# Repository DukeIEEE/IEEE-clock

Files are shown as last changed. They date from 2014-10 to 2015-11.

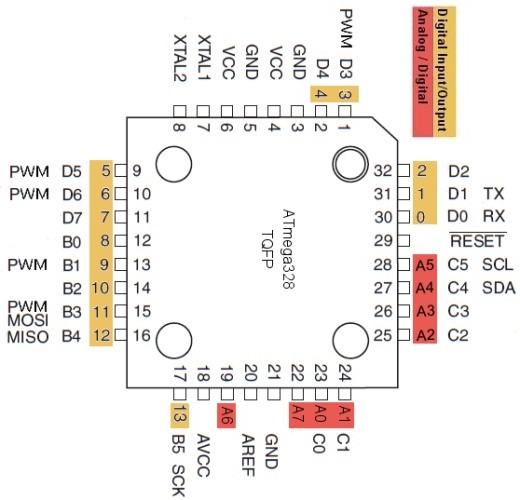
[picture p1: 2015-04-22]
final schematics/atmega328-tqfp-arduino-pinout.jpg

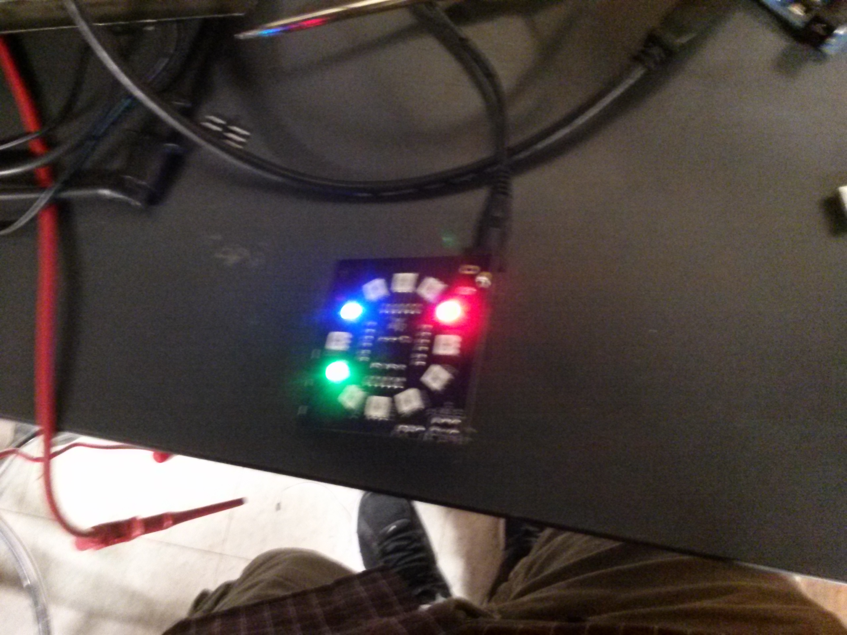
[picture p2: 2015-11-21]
CAM00366.jpg

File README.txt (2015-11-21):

Analog LED clock

This is a project to create a programmable clock using LEDs to represent numbers and hand movements.

Contents:

AnalogClock - Arduino code
Designs - Clock designs for laser cutting
Schematics - PCB schematics and boards
Proposal - Contains a timeline for this workshop
Documents - Contains BOM and datasheets

Programming using arduino-1.0.1 and Arduino UNO programmer:

Place atmega into programmer
Connect all wires except reset to PCB
Upload ArduinoISP -- UNO, Arduino as ISP
Burn bootloader -- Arduino328, Arduino as ISP

Remove atmega from programmer
Connect reset wire
Run a sketch -- Arduino328, AVRISP mkII

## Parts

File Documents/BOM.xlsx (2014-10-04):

4 tactile switches | http://www.digikey.com/product-detail/en/1825910-6/450-1650-ND/1632536
attiny84 | http://www.digikey.com/product-detail/en/ATTINY84-20PU/ATTINY84-20PU-ND/1245916
quartz crystal | http://www.digikey.com/product-highlights/us/en/ecs-international-ecx-crystals/1266
clock chip | http://www.digikey.com/product-detail/en/DS1302S%2BT%26R/DS1302S%2BT%26RTR-ND/1196878

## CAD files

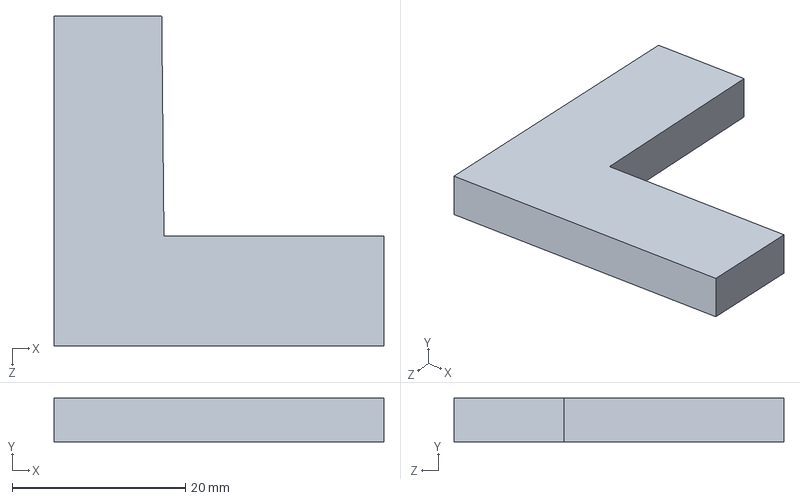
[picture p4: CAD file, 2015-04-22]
Reflow_solder_stencils/Part1.SLDPRT
38.1 x 5.08 x 38.1 mm

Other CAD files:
Designs/Clock_DukeIEEE.dwg
Reflow_solder_stencils/pcb_jig.dwg
Designs/Clock_IEEE.dwg
Designs/Stand_Updated.dwg
Designs/Clock_IEEE_clean.dwg
Designs/Clock_DukeIEEE_clean.dwg
Designs/Basic_Stand_Updated.dwg
Designs/Clock_Duke.dwg
Designs/Clock_Duke_Name.dwg
Designs/Clock_Tom.dwg
Designs/Basic_Stand.dwg
Designs/Clock_Tom2.dwg
Designs/Basic.dwg
Designs/Basic with Screws.dwg
Reflow_solder_stencils/Part1.STL

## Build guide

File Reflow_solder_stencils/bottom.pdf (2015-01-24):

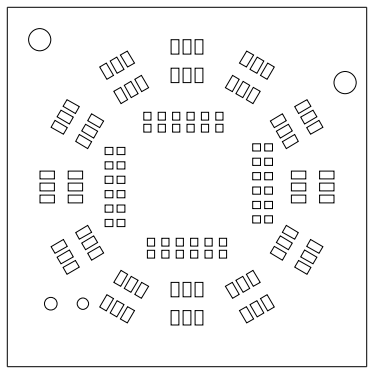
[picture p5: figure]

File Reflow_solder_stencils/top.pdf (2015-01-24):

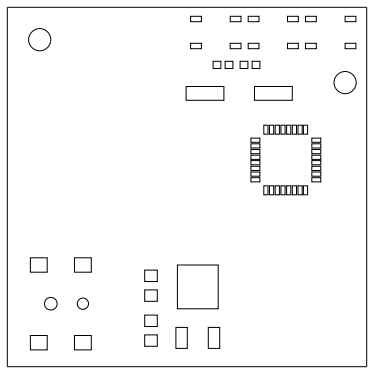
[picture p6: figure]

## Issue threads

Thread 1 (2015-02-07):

how 2 test clock

Ningrui-Li, 2015-02-07:
1. get tom's special version of arduino
2. run strandtest from the Adafrult neopixel libraries.
3. change pin to 5 then upload
4. make sure power pin is connected between clock board and arduino. on clock board, white wire is connected to pin furthest away from the 1 in "ISP1". also black = ground, white = 5 V on arduino.
5. touch red dangling wire to outer middle pin of LED 10 (should be a wire sticking out of it to make this easy)

TomWoo, 2015-04-22:
:+1:

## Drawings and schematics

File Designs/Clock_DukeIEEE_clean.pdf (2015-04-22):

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

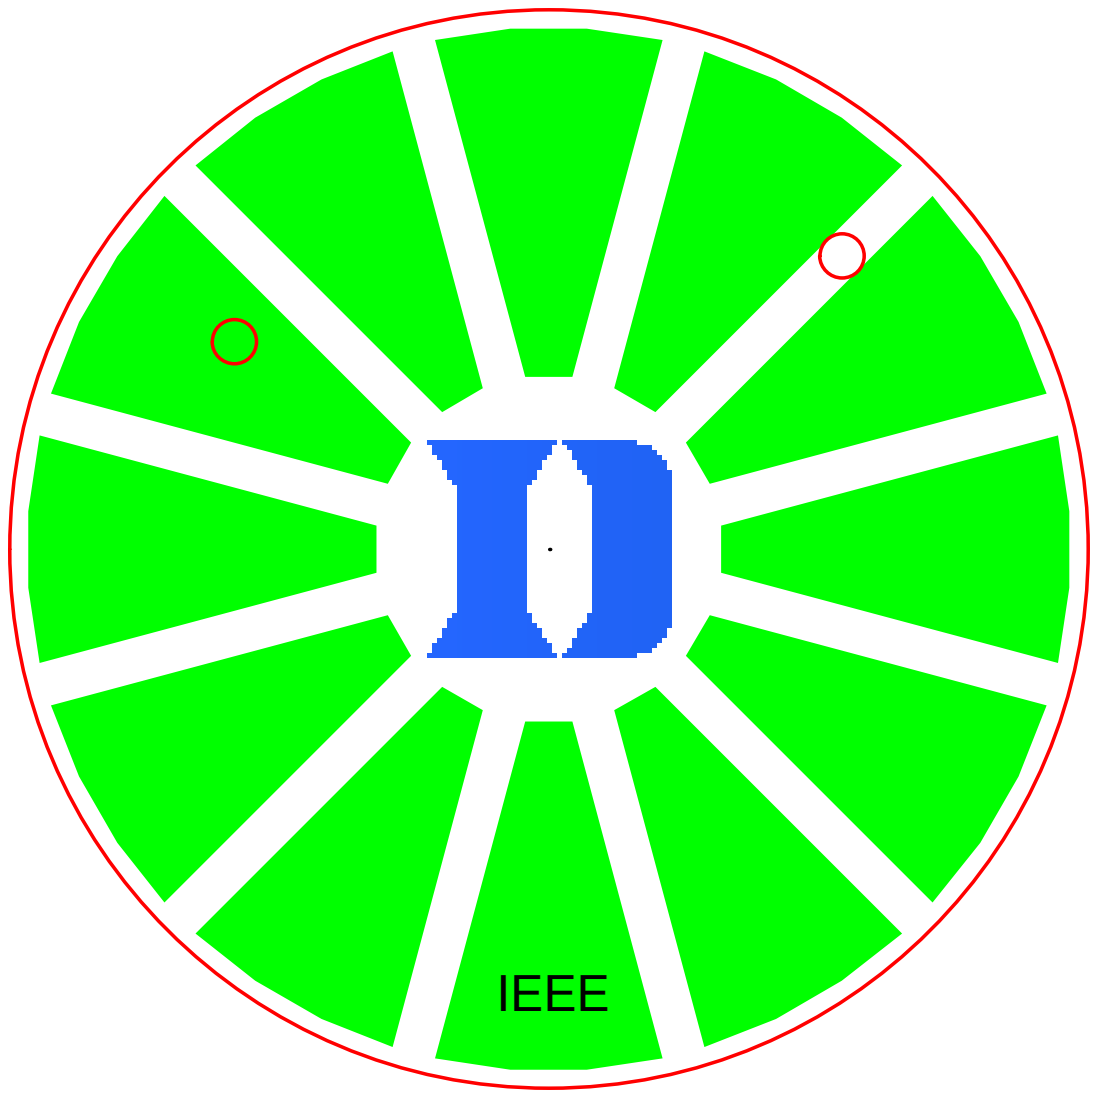
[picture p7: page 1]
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

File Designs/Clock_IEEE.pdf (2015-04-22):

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

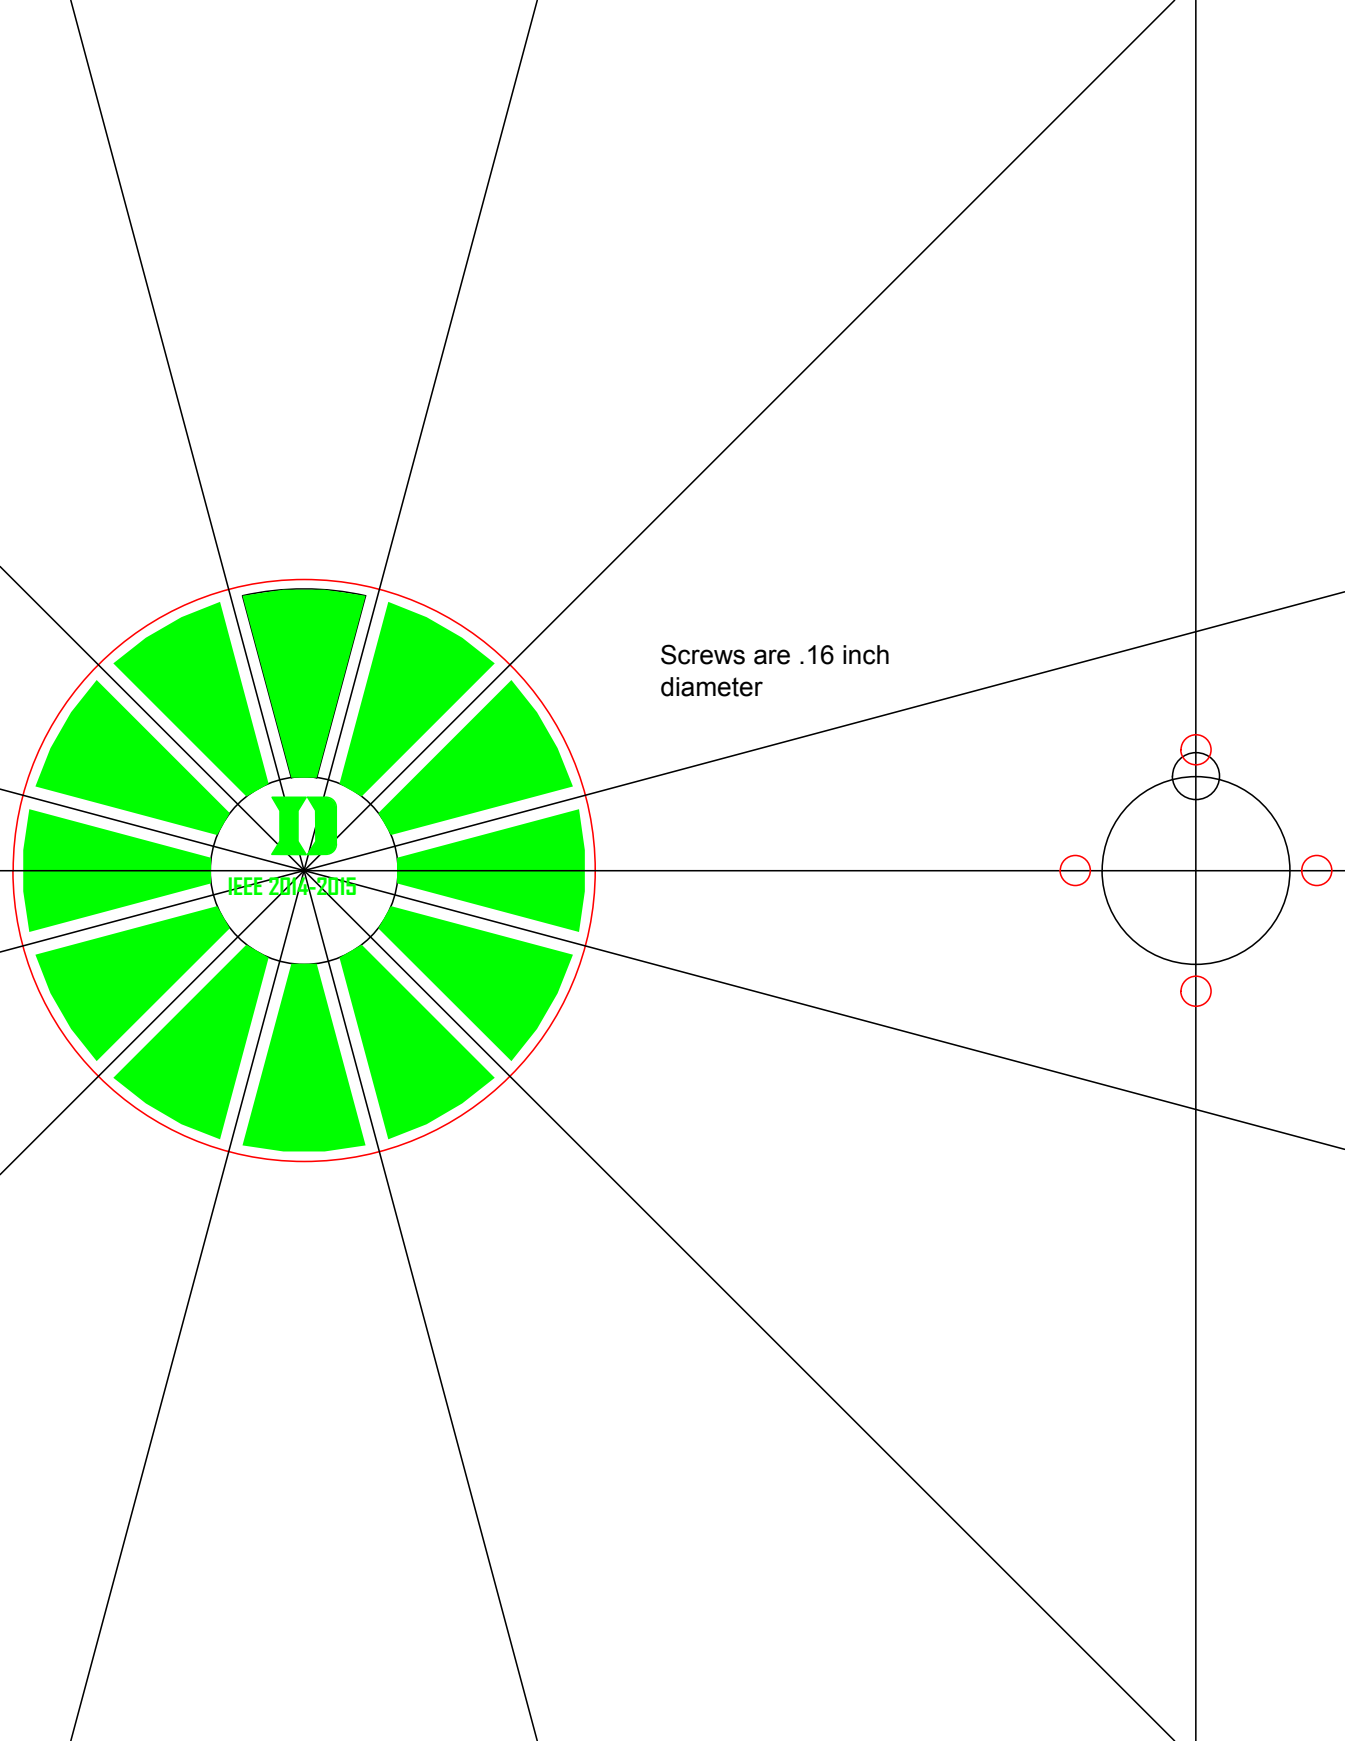
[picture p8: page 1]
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

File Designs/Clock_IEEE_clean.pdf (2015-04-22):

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

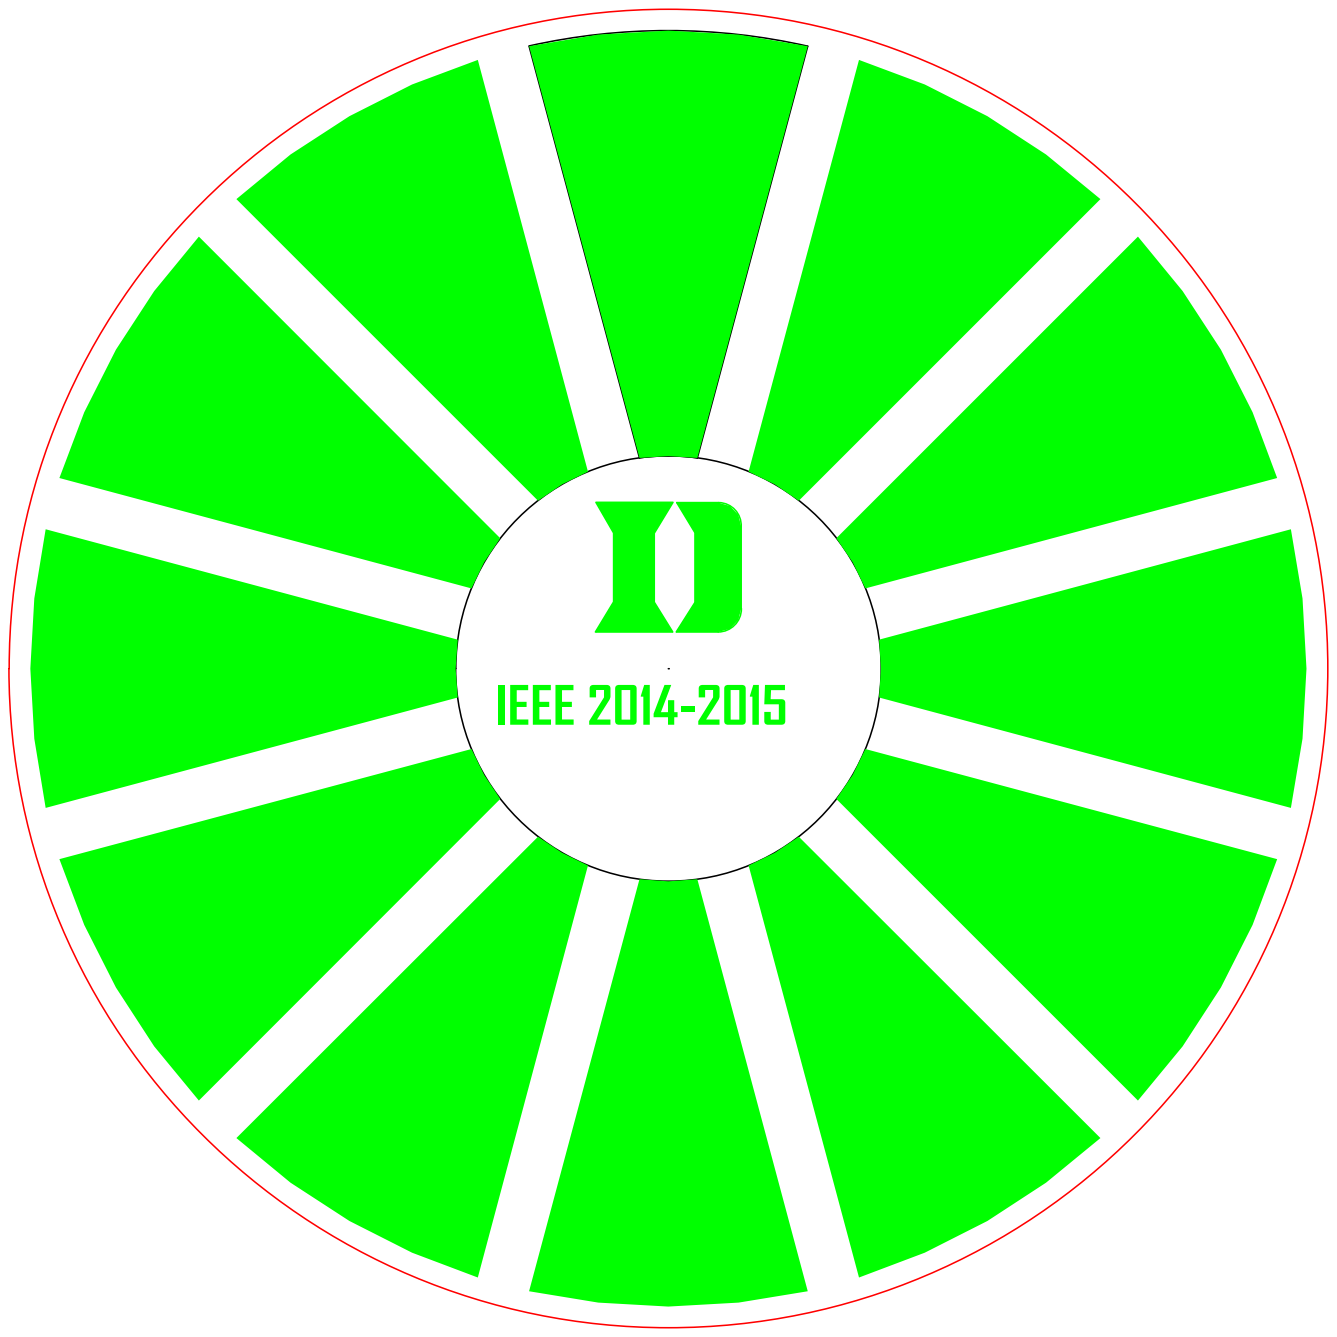
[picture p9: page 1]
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

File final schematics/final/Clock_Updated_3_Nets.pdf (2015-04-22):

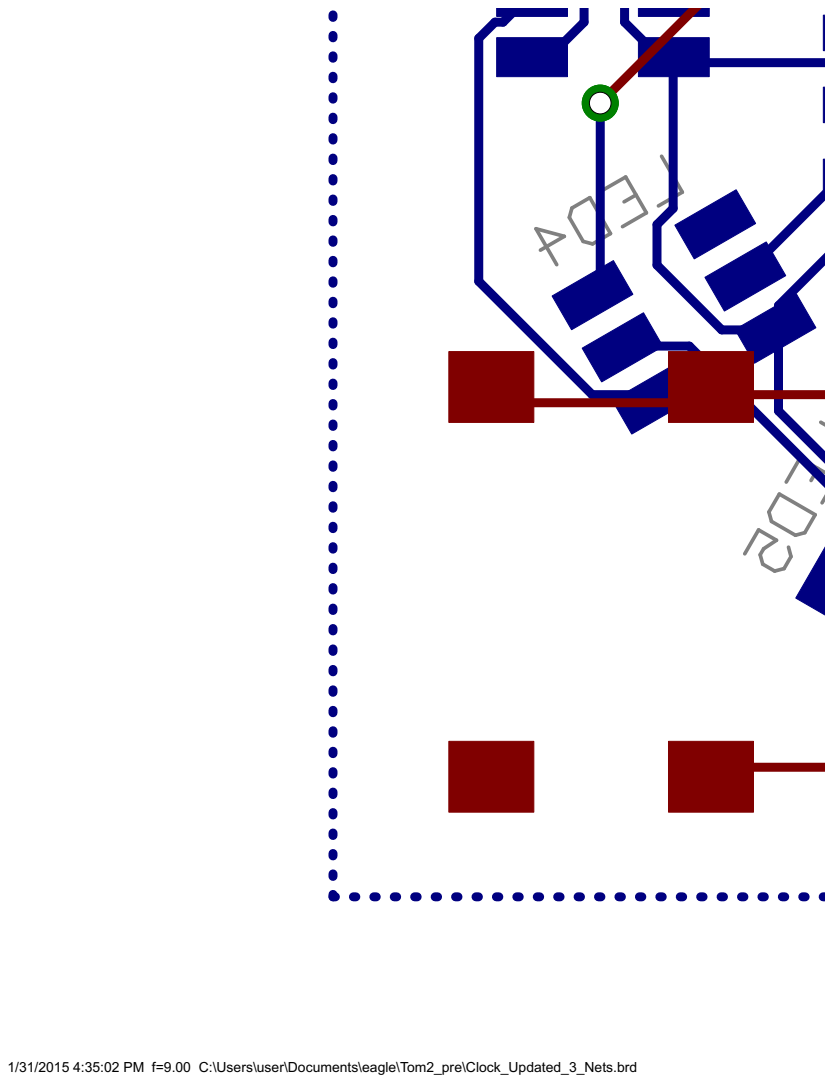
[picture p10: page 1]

1/31/2015 4:35:02 PM f=9.00 C:\Users\user\Documents\eagle\Tom2_pre\Clock_Updated_3_Nets.brd

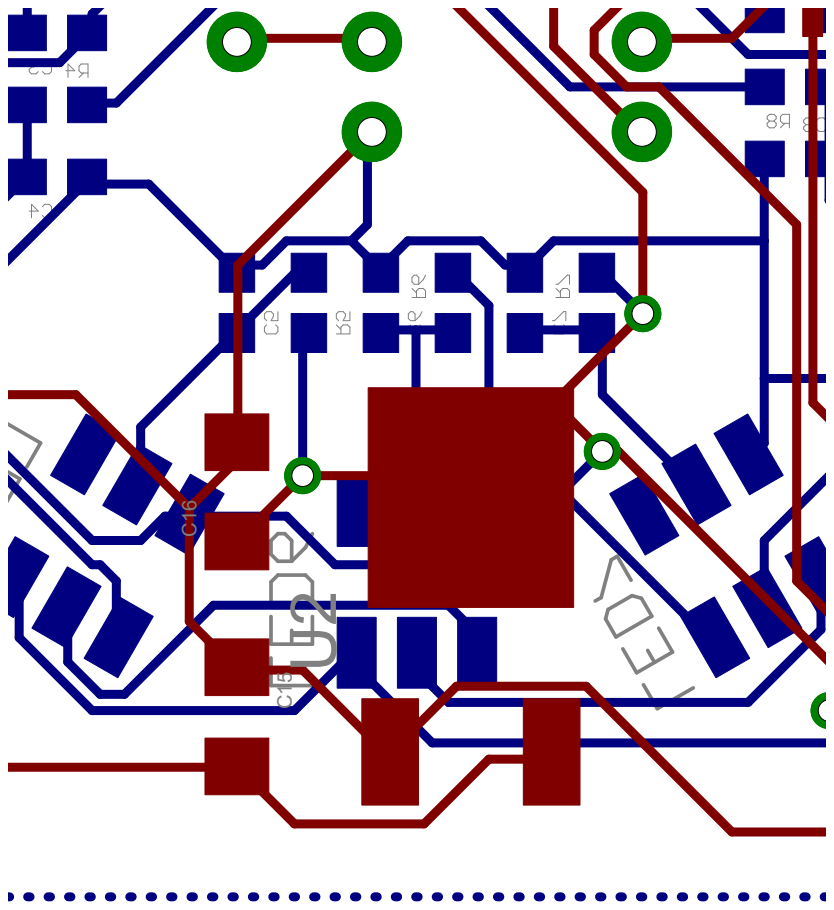
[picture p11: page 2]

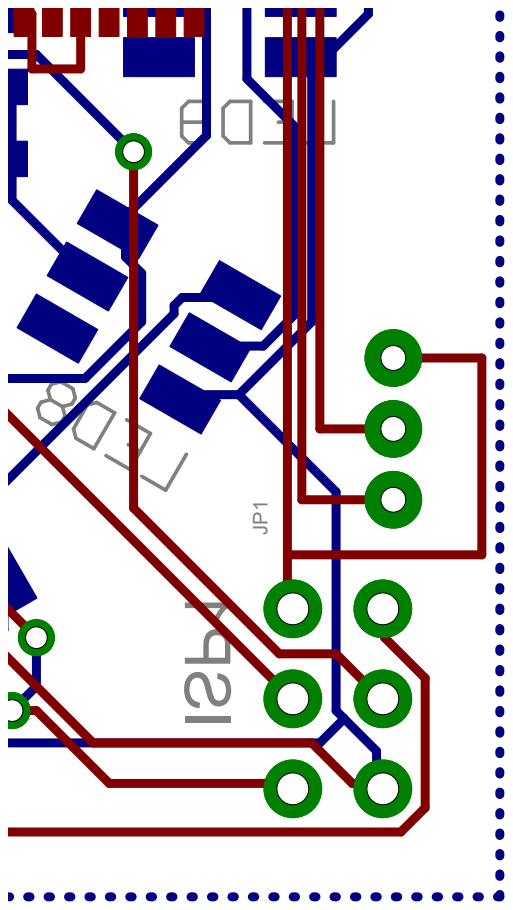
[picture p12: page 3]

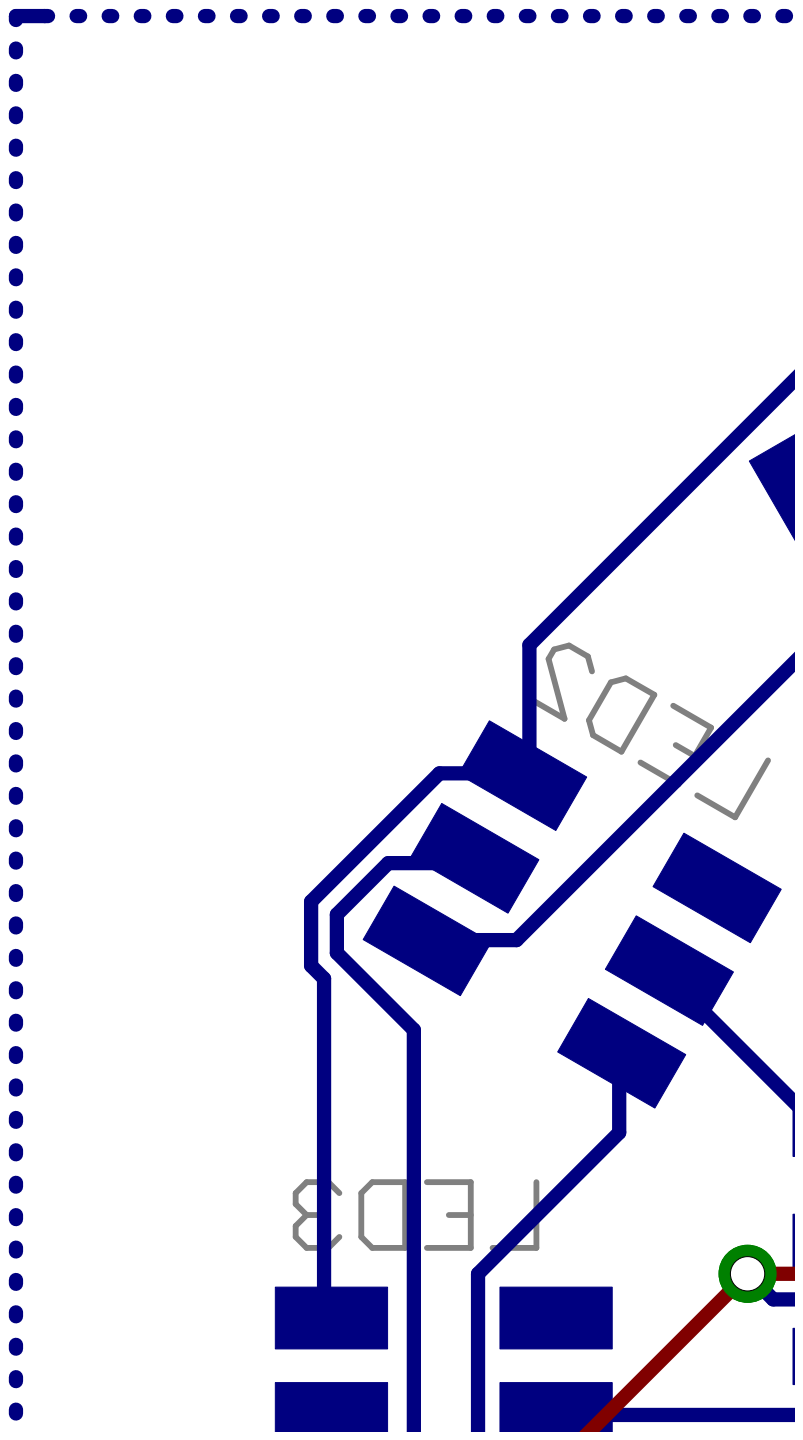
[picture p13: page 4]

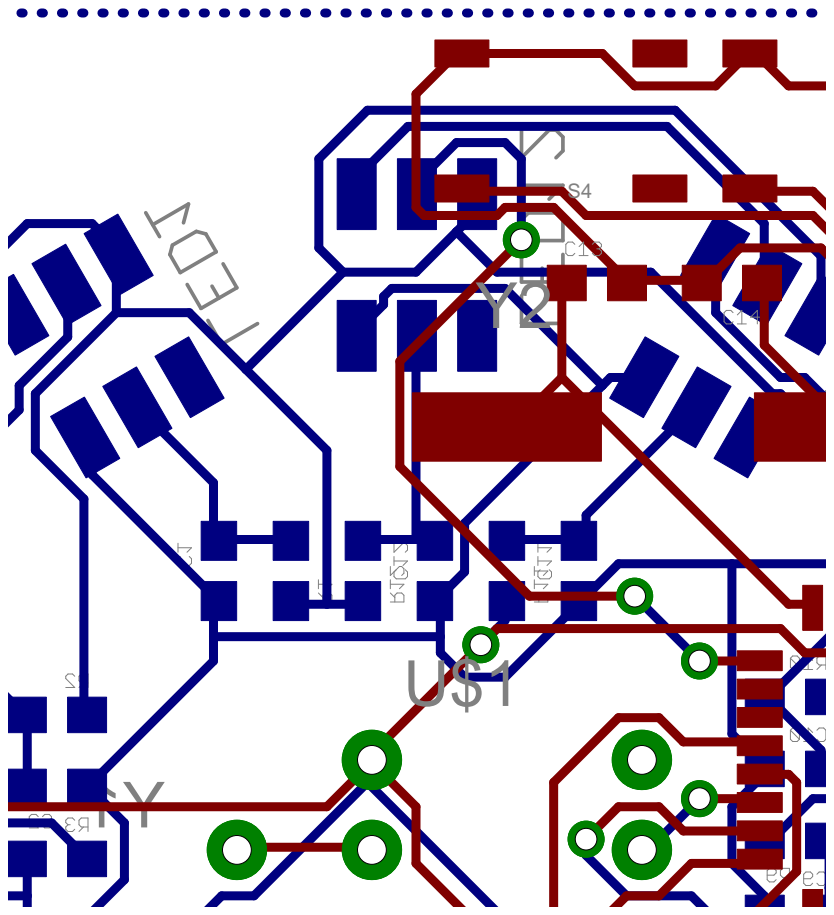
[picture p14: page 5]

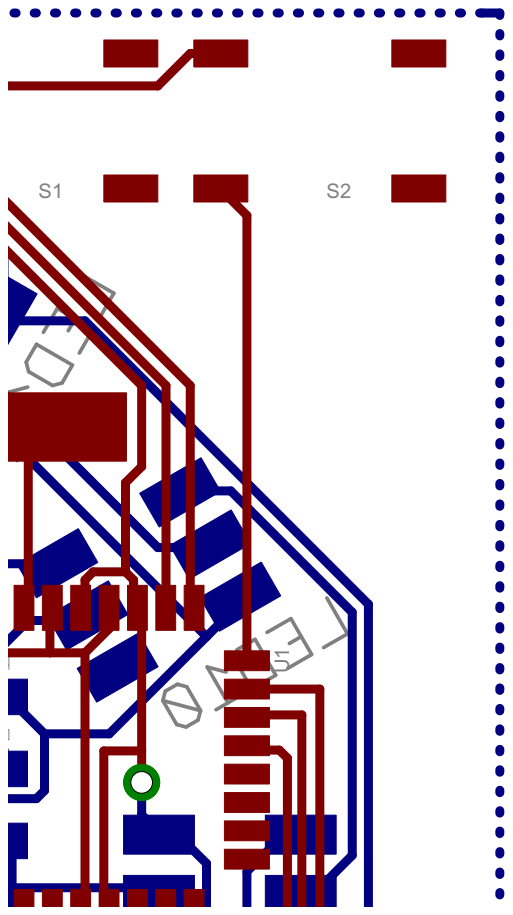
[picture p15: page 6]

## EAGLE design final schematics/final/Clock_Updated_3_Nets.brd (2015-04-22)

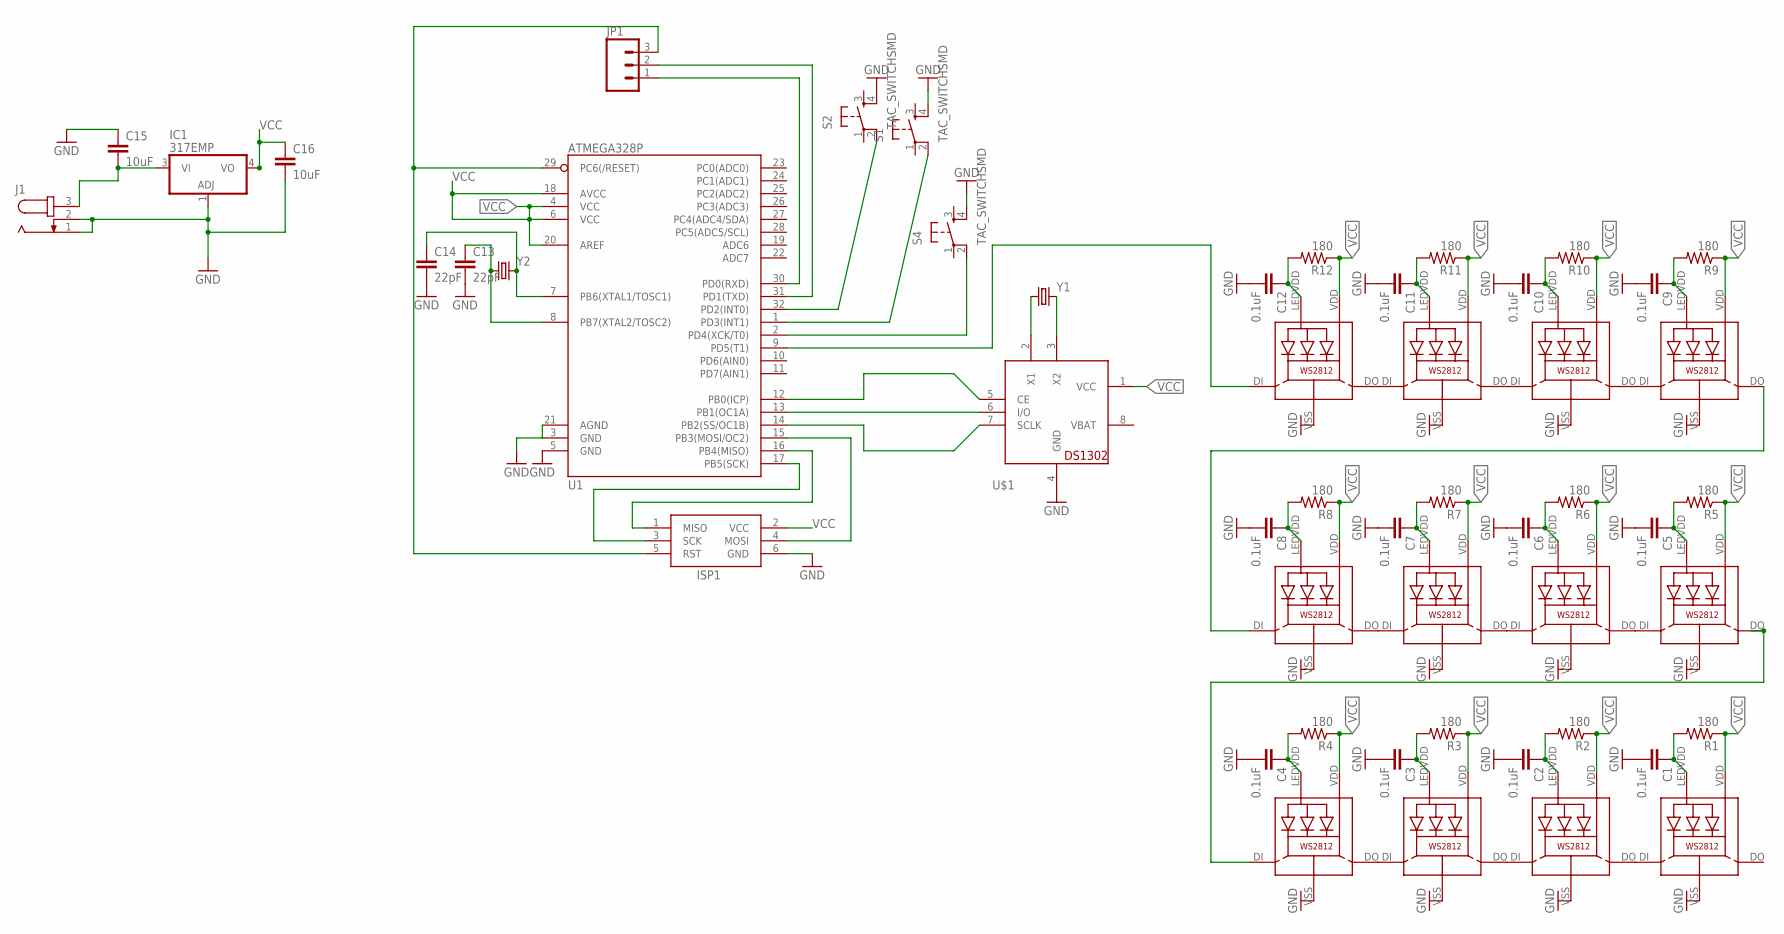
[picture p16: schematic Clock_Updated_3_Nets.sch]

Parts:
C1, C2, C3, C4, C5, C6, C7, C8, C9, C10, C11, C12: 0.1uF; 0603-CAP
C13, C14: 22pF; 0603-CAP
C15, C16: 10uF; 1206
IC1: 317EMP; SOT223
ISP1: AVRISP-6; AVRISP
J1: JACK-PLUG0; SPC4077
JP1: M03JST-PTH-VERT; JST-3-PTH-VERT
LED1, LED2, LED3, LED4, LED5, LED6, LED7, LED8, LED9, LED10, LED11, LED12: WS2812
R1, R2, R3, R4, R5, R6, R7, R8, R9, R10, R11, R12: 180; 0603-RES
S1, S2, S4: TAC_SWITCHSMD; TACTILE-SWITCH-SMD
U1: ATMEGA328P; TQFP32-08
U$1: DS1302; DIL08-ROUND
Y1: CRYSTALTC38H; TC38H
Y2: CRYSTALSMD; HC49UP

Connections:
GND: C1.2, C2.2, C3.2, C4.2, C5.2, C6.2, C7.2, C8.2, C9.2, C10.2, C11.2, C12.2, C13.2, C14.2, C15.1, C16.2, IC1.1 (ADJ), ISP1.6 (GND), J1.1, J1.2, LED1.VSS (GND), LED2.VSS (GND), LED3.VSS (GND), LED4.VSS (GND), LED5.VSS (GND), LED6.VSS (GND), LED7.VSS (GND), LED8.VSS (GND), LED9.VSS (GND), LED10.VSS (GND), LED11.VSS (GND), LED12.VSS (GND), S1.4, S2.4, S4.4, U1.3 (GND), U1.5 (GND), U1.21 (AGND), U$1.4 (GND)
unnamed: ISP1.4 (MOSI), U1.15 (PB3(MOSI/OC2))
unnamed: ISP1.1 (MISO), U1.16 (PB4(MISO))
unnamed: JP1.1, U1.30 (PD0(RXD))
unnamed: S2.2, U1.32 (PD2(INT0))
unnamed: U$1.3 (X2), Y1.2
unnamed: U$1.2 (X1), Y1.1
unnamed: C1.1, LED1.LEDVDD, R1.2
unnamed: C2.1, LED2.LEDVDD, R2.2
unnamed: LED1.DI, LED2.DO
unnamed: C3.1, LED3.LEDVDD, R3.2
unnamed: C4.1, LED4.LEDVDD, R4.2
unnamed: LED3.DI, LED4.DO
unnamed: C5.1, LED5.LEDVDD, R5.2
unnamed: C6.1, LED6.LEDVDD, R6.2
unnamed: LED5.DI, LED6.DO
unnamed: C7.1, LED7.LEDVDD, R7.2
unnamed: C8.1, LED8.LEDVDD, R8.2
unnamed: LED7.DI, LED8.DO
unnamed: C9.1, LED9.LEDVDD, R9.2
unnamed: C10.1, LED10.LEDVDD, R10.2
unnamed: LED9.DI, LED10.DO
unnamed: C11.1, LED11.LEDVDD, R11.2
unnamed: C12.1, LED12.LEDVDD, R12.2
unnamed: LED11.DI, LED12.DO
unnamed: LED4.DI, LED5.DO
unnamed: LED8.DI, LED9.DO
unnamed: JP1.2, U1.31 (PD1(TXD))
unnamed: S1.2, U1.1 (PD3(INT1))
unnamed: U1.13 (PB1(OC1A)), U$1.6 (I/O)
unnamed: U1.12 (PB0(ICP)), U$1.5 (CE)
unnamed: U1.14 (PB2(SS/OC1B)), U$1.7 (SCLK)
unnamed: ISP1.3 (SCK), U1.17 (PB5(SCK))
unnamed: ISP1.5 (RST), JP1.3, U1.29 (PC6(/RESET))
unnamed: S4.2, U1.2 (PD4(XCK/T0))
unnamed: C13.1, U1.8 (PB7(XTAL2/TOSC2)), Y2.1
unnamed: LED2.DI, LED3.DO
unnamed: LED6.DI, LED7.DO
unnamed: LED10.DI, LED11.DO
unnamed: LED12.DI, U1.9 (PD5(T1))
unnamed: C14.1, U1.7 (PB6(XTAL1/TOSC1)), Y2.2
unnamed: C15.2, IC1.3 (VI), J1.3
VBAT: U$1.8 (VBAT)
VCC: C16.1, IC1.4 (VO), ISP1.2 (VCC), LED1.VDD, LED2.VDD, LED3.VDD, LED4.VDD, LED5.VDD, LED6.VDD, LED7.VDD, LED8.VDD, LED9.VDD, LED10.VDD, LED11.VDD, LED12.VDD, R1.1, R2.1, R3.1, R4.1, R5.1, R6.1, R7.1, R8.1, R9.1, R10.1, R11.1, R12.1, U1.4 (VCC), U1.6 (VCC), U1.18 (AVCC), U1.20 (AREF), U$1.1 (VCC)

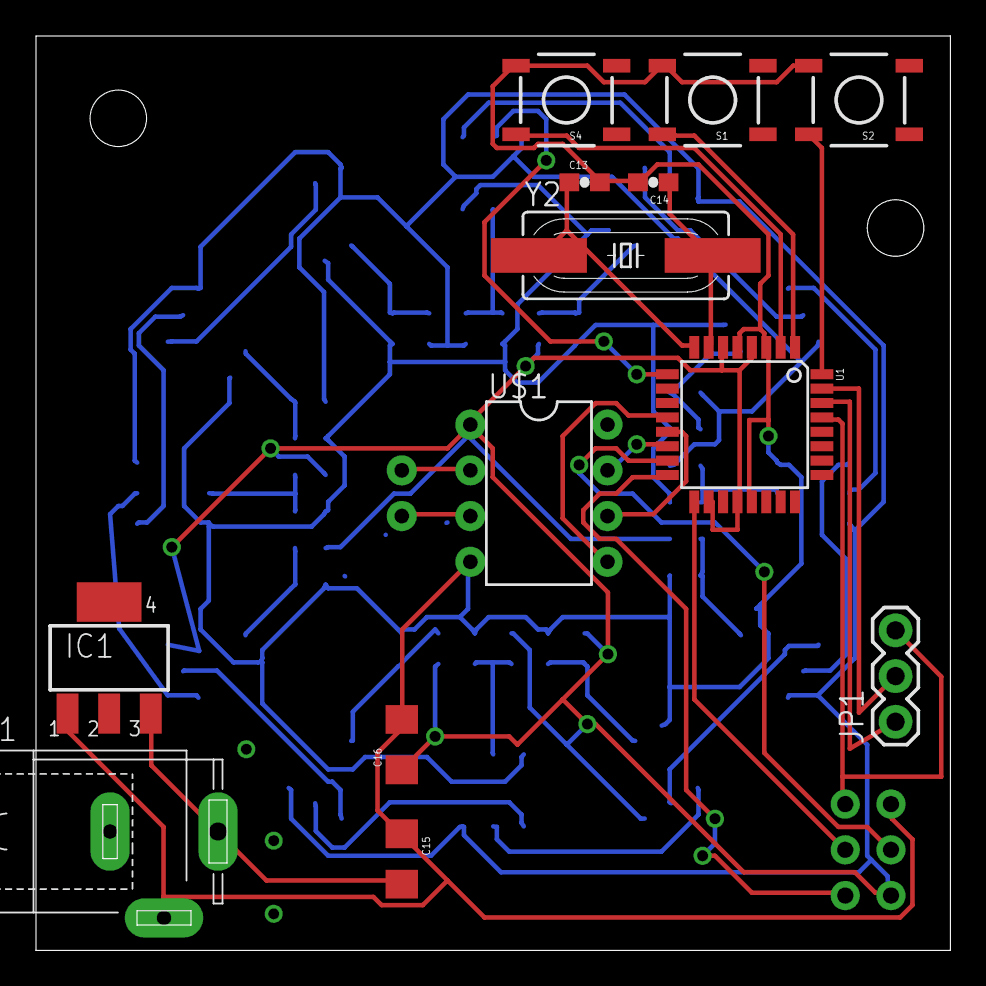
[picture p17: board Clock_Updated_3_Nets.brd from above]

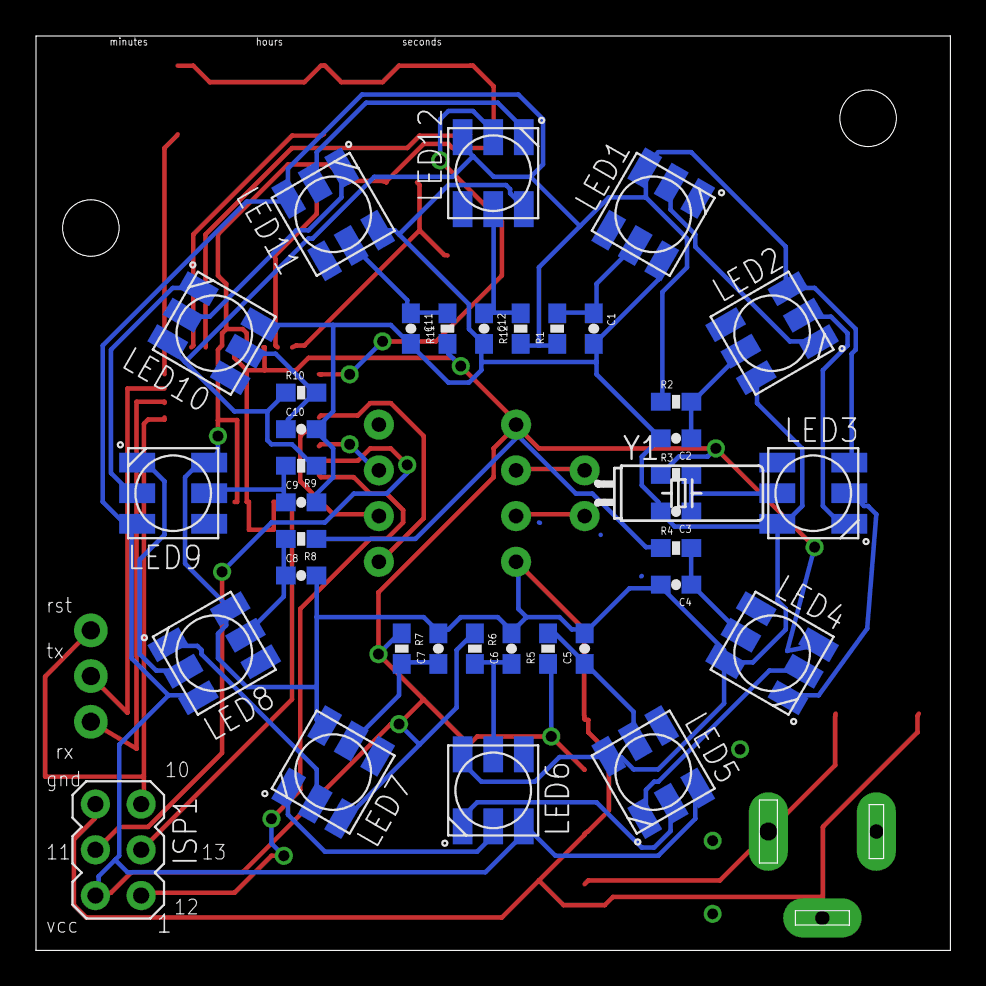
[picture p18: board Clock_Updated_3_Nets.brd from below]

Board: 2 copper layers, 50.8 x 50.8 mm, 51 parts (38 on the bottom side), 43 nets.

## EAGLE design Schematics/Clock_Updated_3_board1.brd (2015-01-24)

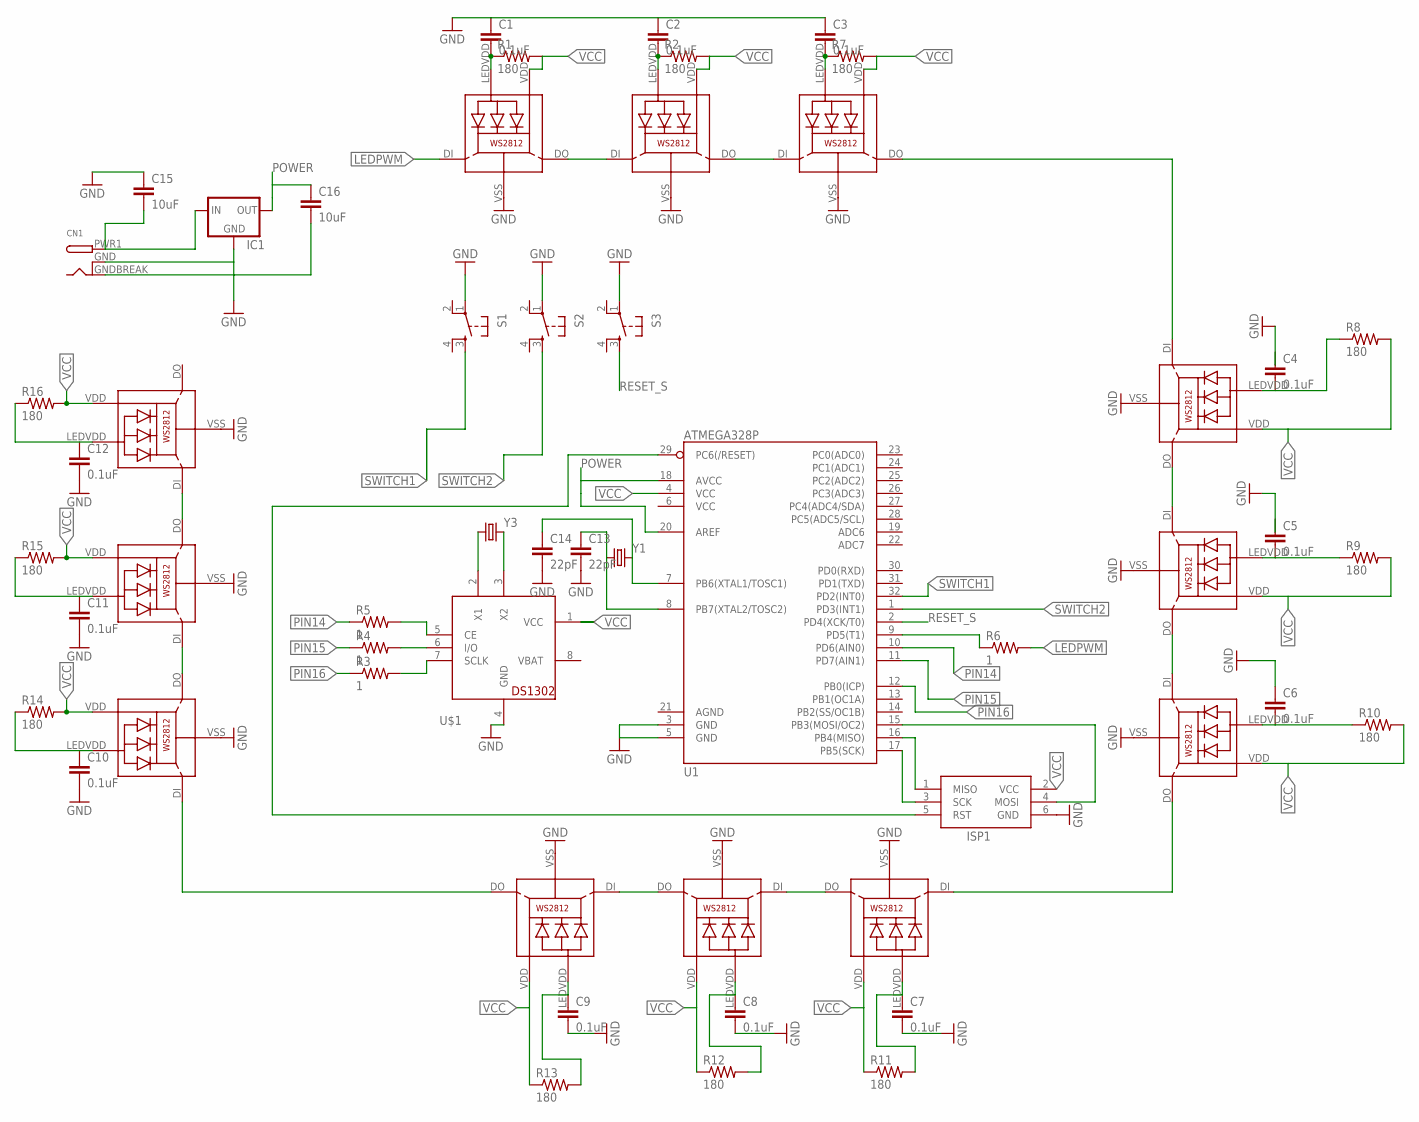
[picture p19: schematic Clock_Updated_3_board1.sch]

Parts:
C1, C2, C3, C4, C5, C6, C7, C8, C9, C10, C11, C12: 0.1uF; 0603-CAP
C13, C14: 22pF; 0603-CAP
C15, C16: 10uF; 1206
CN1: DCBARRELSMT; DCJACK_2MM_SMT
IC1: V_REG_78XX-TO-220; TO-220-ALT
ISP1: AVRISP-6; AVRISP
LED1, LED2, LED3, LED4, LED5, LED6, LED7, LED8, LED9, LED10, LED11, LED12: WS2812
R1, R2, R7, R8, R9, R10, R11, R12, R13, R14, R15, R16: 180; 0603-RES
R3, R4, R5, R6: 1; 0603-RES
S1, S2, S3: TAC_SWITCHPTH; TACTILE-PTH
U1: ATMEGA328P; TQFP32-08
U$1: DS1302; DIL08-ROUND
Y1: CRYSTALSMD; HC49UP
Y3: CRYSTAL32-SMD; CRYSTAL-32KHZ-SMD

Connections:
LEDPWM: LED1.DI, R6.2
unnamed: R6.1, U1.9 (PD5(T1))
unnamed: C4.2, LED5.LEDVDD, R8.1
unnamed: C5.2, LED6.LEDVDD, R9.1
unnamed: C6.2, LED7.LEDVDD, R10.1
unnamed: LED9.DO, LED10.DI
unnamed: LED10.DO, LED11.DI
unnamed: U$1.3 (X2), Y3.X2 (2)
unnamed: U$1.2 (X1), Y3.X1 (1)
unnamed: R3.2, U$1.7 (SCLK)
unnamed: R4.2, U$1.6 (I/O)
unnamed: R5.2, U$1.5 (CE)
unnamed: LED4.DI, LED11.DO
unnamed: LED6.VDD, R9.2
unnamed: LED8.DO, LED12.DI
unnamed: C7.1, LED9.LEDVDD, R11.2
unnamed: LED6.DO, LED7.DI
unnamed: LED3.DO, LED5.DI
unnamed: LED5.DO, LED6.DI
unnamed: LED1.DO, LED2.DI
unnamed: LED2.DO, LED3.DI
unnamed: C8.1, LED10.LEDVDD
unnamed: LED4.DO, LED8.DI
unnamed: C9.1, LED11.LEDVDD, R13.2
unnamed: LED12.LEDVDD, R16.1
unnamed: LED7.DO, LED9.DI
unnamed: LED4.LEDVDD, R14.1
unnamed: ISP1.4 (MOSI), U1.15 (PB3(MOSI/OC2))
unnamed: LED8.LEDVDD, R15.1
unnamed: C1.2, LED1.LEDVDD, R1.1
unnamed: C2.2, LED2.LEDVDD, R2.1
unnamed: C3.2, LED3.LEDVDD, R7.1
unnamed: ISP1.1 (MISO), U1.16 (PB4(MISO))
unnamed: ISP1.3 (SCK), U1.17 (PB5(SCK))
unnamed: ISP1.5 (RST), U1.29 (PC6(/RESET))
unnamed: C15.2, CN1.PWR1 (PWR), IC1.IN
unnamed: C13.1, U1.8 (PB7(XTAL2/TOSC2)), Y1.1
unnamed: C14.1, U1.7 (PB6(XTAL1/TOSC1)), Y1.2
PIN14: R5.1, U1.10 (PD6(AIN0))
PIN15: R4.1, U1.11 (PD7(AIN1))
PIN16: R3.1, U1.12 (PB0(ICP))
POWER: C16.1, IC1.OUT, U1.18 (AVCC), U1.20 (AREF)
RESET_S: S3.3, U1.2 (PD4(XCK/T0))
SWITCH1: S1.3, U1.32 (PD2(INT0))
SWITCH2: S2.3, U1.1 (PD3(INT1))
VBAT: U$1.8 (VBAT)
VCC: ISP1.2 (VCC), LED1.VDD, LED2.VDD, LED3.VDD, LED4.VDD, LED5.VDD, LED7.VDD, LED8.VDD, LED9.VDD, LED10.VDD, LED11.VDD, LED12.VDD, R8.2, R10.2, R11.1, R12.1, R13.1, R14.2, R15.2, R16.2, U1.4 (VCC), U$1.1 (VCC)

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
Board: 2 copper layers, 54 parts (0 on the bottom side), 47 nets, no tracks yet.

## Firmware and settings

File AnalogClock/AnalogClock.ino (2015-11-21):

#include <Adafruit_NeoPixel.h>

#define PIN 5

// Parameter 1 = number of pixels in strip
// Parameter 2 = Arduino pin number (most are valid)
// Parameter 3 = pixel type flags, add together as needed:
//   NEO_KHZ800  800 KHz bitstream (most NeoPixel products w/WS2812 LEDs)
//   NEO_KHZ400  400 KHz (classic 'v1' (not v2) FLORA pixels, WS2811 drivers)
//   NEO_GRB     Pixels are wired for GRB bitstream (most NeoPixel products)
//   NEO_RGB     Pixels are wired for RGB bitstream (v1 FLORA pixels, not v2)
Adafruit_NeoPixel strip = Adafruit_NeoPixel(12, PIN, NEO_GRB + NEO_KHZ800);

// IMPORTANT: To reduce NeoPixel burnout risk, add 1000 uF capacitor across
// pixel power leads, add 300 - 500 Ohm resistor on first pixel's data input
// and minimize distance between Arduino and first pixel.  Avoid connecting
// on a live circuit...if you must, connect GND first.

//--------------------------------------------------------------------------------------------------------------------------------

uint32_t sec_c = strip.Color(32, 0, 0); //second
uint32_t min_c = strip.Color(0, 32, 0); //minute
uint32_t hour_c = strip.Color(0, 0, 32); //hour

//--------------------------------------------------------------------------------------------------------------------------------

// Buttons
const int buttonPin_m = 2;     // the number of the pushbutton pin
const int buttonPin_h = 3;
const int buttonPin_s = 4;

// variables will change:
int buttonState_m = 0;         // variable for reading the pushbutton status
int buttonState_h = 0;

//--------------------------------------------------------------------------------------------------------------------------------

// Set your own pins with these defines !
#define DS1302_SCLK_PIN   10    // Arduino pin for the Serial Clock
#define DS1302_IO_PIN     9    // Arduino pin for the Data I/O
#define DS1302_CE_PIN     8    // Arduino pin for the Chip Enable


// Macros to convert the bcd values of the registers to normal
// integer variables.
// The code uses seperate variables for the high byte and the low byte
// of the bcd, so these macros handle both bytes seperately.
#define bcd2bin(h,l)    (((h)*10) + (l))
#define bin2bcd_h(x)   ((x)/10)
#define bin2bcd_l(x)    ((x)%10)


// Register names.
// Since the highest bit is always '1', 
// the registers start at 0x80
// If the register is read, the lowest bit should be '1'.
#define DS1302_SECONDS           0x80
#define DS1302_MINUTES           0x82
#define DS1302_HOURS             0x84
#define DS1302_DATE              0x86
#define DS1302_MONTH             0x88
#define DS1302_DAY               0x8A
#define DS1302_YEAR              0x8C
#define DS1302_ENABLE            0x8E
#define DS1302_TRICKLE           0x90
#define DS1302_CLOCK_BURST       0xBE
#define DS1302_CLOCK_BURST_WRITE 0xBE
#define DS1302_CLOCK_BURST_READ  0xBF
#define DS1302_RAMSTART          0xC0
#define DS1302_RAMEND            0xFC
#define DS1302_RAM_BURST         0xFE
#define DS1302_RAM_BURST_WRITE   0xFE
#define DS1302_RAM_BURST_READ    0xFF



// Defines for the bits, to be able to change 
// between bit number and binary definition.
// By using the bit number, using the DS1302 
// is like programming an AVR microcontroller.
// But instead of using "(1<<X)", or "_BV(X)", 
// the Arduino "bit(X)" is used.
#define DS1302_D0 0
#define DS1302_D1 1
#define DS1302_D2 2
#define DS1302_D3 3
#define DS1302_D4 4
#define DS1302_D5 5
#define DS1302_D6 6
#define DS1302_D7 7


// Bit for reading (bit in address)
#define DS1302_READBIT DS1302_D0 // READBIT=1: read instruction

// Bit for clock (0) or ram (1) area, 
// called R/C-bit (bit in address)
#define DS1302_RC DS1302_D6

// Seconds Register
#define DS1302_CH DS1302_D7   // 1 = Clock Halt, 0 = start

// Hour Register
#define DS1302_AM_PM DS1302_D5 // 0 = AM, 1 = PM
#define DS1302_12_24 DS1302_D7 // 0 = 24 hour, 1 = 12 hour

// Enable Register
#define DS1302_WP DS1302_D7   // 1 = Write Protect, 0 = enabled

// Trickle Register
#define DS1302_ROUT0 DS1302_D0
#define DS1302_ROUT1 DS1302_D1
#define DS1302_DS0   DS1302_D2
#define DS1302_DS1   DS1302_D2
#define DS1302_TCS0  DS1302_D4
#define DS1302_TCS1  DS1302_D5
#define DS1302_TCS2  DS1302_D6
#define DS1302_TCS3  DS1302_D7


// Structure for the first 8 registers.
// These 8 bytes can be read at once with 
// the 'clock burst' command.
// Note that this structure contains an anonymous union.
// It might cause a problem on other compilers.
typedef struct ds1302_struct
{
  uint8_t Seconds:4;      // low decimal digit 0-9
  uint8_t Seconds10:3;    // high decimal digit 0-5
  uint8_t CH:1;           // CH = Clock Halt
  uint8_t Minutes:4;
  uint8_t Minutes10:3;
  uint8_t reserved1:1;
  union
  {
    struct
    {
      uint8_t Hour:4;
      uint8_t Hour10:2;
      uint8_t reserved2:1;
      uint8_t hour_12_24:1; // 0 for 24 hour format
    } h24;
    struct
    {
      uint8_t Hour:4;
      uint8_t Hour10:1;
      uint8_t AM_PM:1;      // 0 for AM, 1 for PM
      uint8_t reserved2:1;
      uint8_t hour_12_24:1; // 1 for 12 hour format
    } h12;
  };
  uint8_t Date:4;           // Day of month, 1 = first day
  uint8_t Date10:2;
  uint8_t reserved3:2;
  uint8_t Month:4;          // Month, 1 = January
  uint8_t Month10:1;
  uint8_t reserved4:3;
  uint8_t Day:3;            // Day of week, 1 = first day (any day)
  uint8_t reserved5:5;
  uint8_t Year:4;           // Year, 0 = year 2000
  uint8_t Year10:4;
  uint8_t reserved6:7;
  uint8_t WP:1;             // WP = Write Protect
};

//-------------------------------------------------------------------------------------------------------------------------------- setup

void setup()
{      
  ds1302_struct rtc;


  Serial.begin(9600);
  Serial.println(F("DS1302 Real Time Clock"));
  Serial.println(F("Version 2, March 2013"));


  // Start by clearing the Write Protect bit
  // Otherwise the clock data cannot be written
  // The whole register is written, 
  // but the WP-bit is the only bit in that register.
  DS1302_write (DS1302_ENABLE, 0);

  // Disable Trickle Charger.
  DS1302_write (DS1302_TRICKLE, 0x00);

  // Remove the next define, 
  // after the right date and time are set.
  #define SET_DATE_TIME_JUST_ONCE
  #ifdef SET_DATE_TIME_JUST_ONCE  

  // Fill these variables with the date and time.
  int seconds, minutes, hours, dayofweek, dayofmonth, month, year;

  // Example for april 15, 2013, 10:08, monday is 2nd day of Week.
  // Set your own time and date in these variables.
  seconds    = 0;
  minutes    = 0;
  hours      = 1;
  dayofweek  = 1;  // Day of week, any day can be first, counts 1...7
  dayofmonth = 1; // Day of month, 1...31
  month      = 1;  // month 1...12
  year       = 2013;

  // Set a time and date
  // This also clears the CH (Clock Halt) bit, 
  // to start the clock.

  // Fill the structure with zeros to make 
  // any unused bits zero
  memset ((char *) &rtc, 0, sizeof(rtc));

  rtc.Seconds    = bin2bcd_l( seconds);
  rtc.Seconds10  = bin2bcd_h( seconds);
  rtc.CH         = 0;      // 1 for Clock Halt, 0 to run;
  rtc.Minutes    = bin2bcd_l( minutes);
  rtc.Minutes10  = bin2bcd_h( minutes);
  // To use the 12 hour format,
  // use it like these four lines:
  rtc.h12.Hour   = bin2bcd_l( hours);
  rtc.h12.Hour10 = bin2bcd_h( hours);
  rtc.h12.AM_PM  = 0;     // AM = 0
  rtc.h12.hour_12_24 = 1; // 1 for 24 hour format
//  rtc.h24.Hour   = bin2bcd_l( hours);
//  rtc.h24.Hour10 = bin2bcd_h( hours);
//  rtc.h24.hour_12_24 = 0; // 0 for 24 hour format
  rtc.Date       = bin2bcd_l( dayofmonth);
  rtc.Date10     = bin2bcd_h( dayofmonth);
  rtc.Month      = bin2bcd_l( month);
  rtc.Month10    = bin2bcd_h( month);
  rtc.Day        = dayofweek;
  rtc.Year       = bin2bcd_l( year - 2000);
  rtc.Year10     = bin2bcd_h( year - 2000);
  rtc.WP = 0;  

  // Write all clock data at once (burst mode).
  DS1302_clock_burst_write( (uint8_t *) &rtc);
#endif



  strip.begin();
  strip.show(); // Initialize all pixels to 'off'
  
  
  
    // initialize the pushbutton pin as an input:
  pinMode(buttonPin_m, INPUT_PULLUP);
  pinMode(buttonPin_h, INPUT_PULLUP);
  pinMode(buttonPin_s, INPUT_PULLUP);
}

//-------------------------------------------------------------------------------------------------------------------------------- loop

void loop()
{
//  ds1302_struct rtc;
//  char buffer[80];     // the code uses 70 characters.

  // Read all clock data at once (burst mode).
//  DS1302_clock_burst_read( (uint8_t *) &rtc);

//  sprintf( buffer, "Time = %02d:%02d:%02d, ", \
//    bcd2bin( rtc.h12.Hour10, rtc.h12.Hour), \
//    bcd2bin( rtc.Minutes10, rtc.Minutes), \
//    bcd2bin( rtc.Seconds10, rtc.Seconds));
//  Serial.print(buffer);
//
//  sprintf(buffer, "Date(day of month) = %d, Month = %d, " \
//    "Day(day of week) = %d, Year = %d", \
//    bcd2bin( rtc.Date10, rtc.Date), \
//    bcd2bin( rtc.Month10, rtc.Month), \
//    rtc.Day, \
//    2000 + bcd2bin( rtc.Year10, rtc.Year));
//  Serial.println( buffer);

  myDelay(1000);
//  delay(1000);
}

ds1302_struct rtc;
int s, old_s, m, h;
unsigned long dim = 1;
unsigned long startCheck, endCheck;
// myDelay is supposed to find the current time (s for seconds, m for minutes, and h for hours)
// then updateClock()
// then check for button-presses most of the time
// I'm having trouble with buttons, so I commented out the last three lines of code in this function.
void myDelay(unsigned long duration) {
  checkButtons();

  int old_s = s;
  DS1302_clock_burst_read( (uint8_t *) &rtc);
  s = bcd2bin(rtc.Seconds10, rtc.Seconds);
  
  if (s != old_s && s % 5 == 0){
    startCheck = millis();
  }
  
  m = bcd2bin(rtc.Minutes10, rtc.Minutes);
  h = bcd2bin(rtc.h12.Hour10, rtc.h12.Hour);  
  updateClock();
  
//  unsigned long start = millis();
//  while (millis() - start <= duration) {
//  }
}

// Updates the clock given (s,m,h) values
// Keep in mind that we'll need to rewrite this code for a 12-LED strip (remove hour_index = h)
// This function works properly unless checkButtons() is called.
void updateClock() {
//  Serial.print(s);
//  Serial.print(' ');
//  Serial.print(m);
//  Serial.print(' ');
//  Serial.println(h);
  
  for(int i=0; i<strip.numPixels(); i++) {
    strip.setPixelColor(i, 0);
  }
  //strip.show();
  
//  strip.setPixelColor(0, strip.Color(0,0,0));
//  strip.setPixelColor(0, strip.Color(1,1,1));
  //for(int i = 0; i < 10; ++i) {
  //  strip.setPixelColor(s-i, strip.Color((int)(255*(1-colorFading*i/10)), 0, 0));
  //}
  
  // set offset = 0 if first LED on strip is broken.
  int offset = 0;
  // divide by 5 and add offset to use only 12 LEDs on strip.
  // also done for minutes.
  int s_led = s / 5 + offset;
  int m_led = m / 5 + offset;
  int h_led = h - 1 + offset;
  float dimScale = (float)(dim*.5);
  int prev_s_led;
  if (s_led == offset)
    prev_s_led = (11 + offset);
  else
    prev_s_led = s_led - 1; 
    
  int prev_m_led;
  if (m_led == offset)
    prev_m_led = (11 + offset);
  else
    prev_m_led = m_led - 1;  
    
  int prev_h_led;
  if (h_led == offset)
    prev_h_led = (11 + offset);
  else
    prev_h_led = h_led - 1;  
    
  endCheck = millis();
  float s_colorFading = (endCheck-startCheck)/(5000.0);
  float m_colorFading = ((float)(s + (m % 5)*60) / 300.0);
  float h_colorFading = ((float)m / 60.0);
  
  strip.setPixelColor(11-prev_s_led, strip.getPixelColor(11-prev_s_led) + strip.Color((int)(32*dimScale*(1-s_colorFading)), 0, 0));
  strip.setPixelColor(11-s_led, strip.getPixelColor(11-s_led) + strip.Color((int)(32*dimScale*s_colorFading), 0, 0));
  strip.setPixelColor(11-prev_m_led, strip.getPixelColor(11-prev_m_led) + strip.Color(0, (int)(32*dimScale*(1-m_colorFading)), 0));
  strip.setPixelColor(11-m_led, strip.getPixelColor(11-m_led) + strip.Color(0, (int)(32*dimScale*m_colorFading), 0));
  //Serial.println((int)(32*m_colorFading));
  
  strip.setPixelColor(11-prev_h_led, strip.getPixelColor(11-prev_h_led) + strip.Color(0, 0, (int)(32*dimScale*(1-h_colorFading))));
  strip.setPixelColor(11-h_led, strip.getPixelColor(11-h_led) + strip.Color(0, 0, (int)(32*dimScale*h_colorFading)));
  strip.show();

  //strip.setPixelColor(s, sec_c);
  //strip.setPixelColor(m, strip.getPixelColor(m)+min_c);
  //int hour_index = 5*h + m/12;
  //strip.setPixelColor(hour_index, strip.getPixelColor(hour_index)+hour_c);
  //strip.show();
  
//  Serial.println(5*h + m/12);
  
  //delay(10);
}

unsigned long buttonDelay = 300; // Minimum time before button-press can be registered again
// (not a good button system because it doesn't allow continuous button-holding changes, so someone help us fix this)
unsigned long lastPressedTime_m = 0, lastPressedTime_h = 0, lastPressedTime_s = 0;
//boolean m_depressed = false, h_depressed = false; // store button states (1 - depressed, 0 - not depressed)

// Check to see if H/M or S-reset pressed
void checkButtons() {
  // reset seconds to 0
  if (digitalRead(buttonPin_h)==0 && digitalRead(buttonPin_m)==0){
    s = 0;
    rtc.Seconds = bin2bcd_l(s);
    rtc.Seconds10 = bin2bcd_h(s);
    
    DS1302_clock_burst_write((uint8_t *)&rtc);
    startCheck = millis();
    lastPressedTime_s = millis();
  }
  
  else if((millis()-lastPressedTime_s > buttonDelay) && (digitalRead(buttonPin_s)==0)) { // reset button (for seconds) press detected
    if (dim < 4)
      dim += 1;
    else
      dim = 1;
    Serial.println(dim);
    lastPressedTime_s = millis();
  }
  
  else if((millis()-lastPressedTime_m > buttonDelay) && (digitalRead(buttonPin_m)==0)) { // button press detected
//  Serial.println('m');
  //  Serial.print(m);
  //  Serial.print(' ');
    m++;
  //  Serial.print("Minute:");
  //  Serial.print(m);
  //  Serial.println("Hour: ");
   // Serial.print(h);
    
    if(m>=60) {
      m = 0;
    }
    rtc.Minutes = bin2bcd_l(m);
    rtc.Minutes10 = bin2bcd_h(m);
    
    DS1302_clock_burst_write((uint8_t *)&rtc);
    startCheck = millis();
    lastPressedTime_m = millis();
  }
  
  else if((millis()-lastPressedTime_h > buttonDelay) && (digitalRead(buttonPin_h)==0)) { // button press detected
//  Serial.println('h');
//    Serial.print(h);
//    Serial.print(' ');
    h++;
//    Serial.print(h);
//    Serial.println(' ');
    if(h>12) {
      h = 1;
    }
    rtc.h12.Hour = bin2bcd_l(h);
    rtc.h12.Hour10 = bin2bcd_h(h);
    
    DS1302_clock_burst_write((uint8_t *)&rtc);
    startCheck = millis();
    lastPressedTime_h = millis();
  }
}

//--------------------------------------------------------------------------------------------------------------------------------

// --------------------------------------------------------
// DS1302_clock_burst_read
//
// This function reads 8 bytes clock data in burst mode
// from the DS1302.
//
// This function may be called as the first function, 
// also the pinMode is set.
//
void DS1302_clock_burst_read( uint8_t *p)
{
  int i;

  _DS1302_start();

  // Instead of the address, 
  // the CLOCK_BURST_READ command is issued
  // the I/O-line is released for the data
  _DS1302_togglewrite( DS1302_CLOCK_BURST_READ, true);  

  for( i=0; i<8; i++)
  {
    *p++ = _DS1302_toggleread();
  }
  _DS1302_stop();
}


// --------------------------------------------------------
// DS1302_clock_burst_write
//
// This function writes 8 bytes clock data in burst mode
// to the DS1302.
//
// This function may be called as the first function, 
// also the pinMode is set.
//
void DS1302_clock_burst_write( uint8_t *p)
{
  int i;

  _DS1302_start();

  // Instead of the address, 
  // the CLOCK_BURST_WRITE command is issued.
  // the I/O-line is not released
  _DS1302_togglewrite( DS1302_CLOCK_BURST_WRITE, false);  

  for( i=0; i<8; i++)
  {
    // the I/O-line is not released
    _DS1302_togglewrite( *p++, false);  
  }
  _DS1302_stop();
}


// --------------------------------------------------------
// DS1302_read
//
// This function reads a byte from the DS1302 
// (clock or ram).
//
// The address could be like "0x80" or "0x81", 
// the lowest bit is set anyway.
//
// This function may be called as the first function, 
// also the pinMode is set.
//
uint8_t DS1302_read(int address)
{
  uint8_t data;

  // set lowest bit (read bit) in address
  bitSet( address, DS1302_READBIT);  

  _DS1302_start();
  // the I/O-line is released for the data
  _DS1302_togglewrite( address, true);  
  data = _DS1302_toggleread();
  _DS1302_stop();

  return (data);
}


// --------------------------------------------------------
// DS1302_write
//
// This function writes a byte to the DS1302 (clock or ram).
//
// The address could be like "0x80" or "0x81", 
// the lowest bit is cleared anyway.
//
// This function may be called as the first function, 
// also the pinMode is set.
//
void DS1302_write( int address, uint8_t data)
{
  // clear lowest bit (read bit) in address
  bitClear( address, DS1302_READBIT);   

  _DS1302_start();
  // don't release the I/O-line
  _DS1302_togglewrite( address, false); 
  // don't release the I/O-line
  _DS1302_togglewrite( data, false); 
  _DS1302_stop();  
}


// --------------------------------------------------------
// _DS1302_start
//
// A helper function to setup the start condition.
//
// An 'init' function is not used.
// But now the pinMode is set every time.
// That's not a big deal, and it's valid.
// At startup, the pins of the Arduino are high impedance.
// Since the DS1302 has pull-down resistors, 
// the signals are low (inactive) until the DS1302 is used.
void _DS1302_start( void)
{
  digitalWrite( DS1302_CE_PIN, LOW); // default, not enabled
  pinMode( DS1302_CE_PIN, OUTPUT);  

  digitalWrite( DS1302_SCLK_PIN, LOW); // default, clock low
  pinMode( DS1302_SCLK_PIN, OUTPUT);

  pinMode( DS1302_IO_PIN, OUTPUT);

  digitalWrite( DS1302_CE_PIN, HIGH); // start the session
  delayMicroseconds( 4);           // tCC = 4us
}


// --------------------------------------------------------
// _DS1302_stop
//
// A helper function to finish the communication.
//
void _DS1302_stop(void)
{
  // Set CE low
  digitalWrite( DS1302_CE_PIN, LOW);

  delayMicroseconds( 4);           // tCWH = 4us
}


// --------------------------------------------------------
// _DS1302_toggleread
//
// A helper function for reading a byte with bit toggle
//
// This function assumes that the SCLK is still high.
//
uint8_t _DS1302_toggleread( void)
{
  uint8_t i, data;

  data = 0;
  for( i = 0; i <= 7; i++)
  {
    // Issue a clock pulse for the next databit.
    // If the 'togglewrite' function was used before 
    // this function, the SCLK is already high.
    digitalWrite( DS1302_SCLK_PIN, HIGH);
    delayMicroseconds( 1);

    // Clock down, data is ready after some time.
    digitalWrite( DS1302_SCLK_PIN, LOW);
    delayMicroseconds( 1);        // tCL=1000ns, tCDD=800ns

    // read bit, and set it in place in 'data' variable
    bitWrite( data, i, digitalRead( DS1302_IO_PIN)); 
  }
  return( data);
}


// --------------------------------------------------------
// _DS1302_togglewrite
//
// A helper function for writing a byte with bit toggle
//
// The 'release' parameter is for a read after this write.
// It will release the I/O-line and will keep the SCLK high.
//
void _DS1302_togglewrite( uint8_t data, uint8_t release)
{
  int i;

  for( i = 0; i <= 7; i++)
  { 
    // set a bit of the data on the I/O-line
    digitalWrite( DS1302_IO_PIN, bitRead(data, i));  
    delayMicroseconds( 1);     // tDC = 200ns

    // clock up, data is read by DS1302
    digitalWrite( DS1302_SCLK_PIN, HIGH);     
    delayMicroseconds( 1);     // tCH = 1000ns, tCDH = 800ns

    if( release && i == 7)
    {
      // If this write is followed by a read, 
      // the I/O-line should be released after 
      // the last bit, before the clock line is made low.
      // This is according the datasheet.
      // I have seen other programs that don't release 
      // the I/O-line at this moment,
      // and that could cause a shortcut spike 
      // on the I/O-line.
      pinMode( DS1302_IO_PIN, INPUT);

      // For Arduino 1.0.3, removing the pull-up is no longer needed.
      // Setting the pin as 'INPUT' will already remove the pull-up.
      // digitalWrite (DS1302_IO, LOW); // remove any pull-up  
    }
    else
    {
      digitalWrite( DS1302_SCLK_PIN, LOW);
      delayMicroseconds( 1);       // tCL=1000ns, tCDD=800ns
    }
  }
}

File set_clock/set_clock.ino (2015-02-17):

// Example sketch for interfacing with the DS1302 timekeeping chip.
//
// Copyright (c) 2009, Matt Sparks
// All rights reserved.
//
// http://quadpoint.org/projects/arduino-ds1302
#include <stdio.h>
#include <DS1302.h>

namespace {

// Set the appropriate digital I/O pin connections. These are the pin
// assignments for the Arduino as well for as the DS1302 chip. See the DS1302
// datasheet:
//
//   http://datasheets.maximintegrated.com/en/ds/DS1302.pdf
const int kCePin   = 8;  // Chip Enable
const int kIoPin   = 9;  // Input/Output
const int kSclkPin = 10;  // Serial Clock

// Create a DS1302 object.
DS1302 rtc(kCePin, kIoPin, kSclkPin);

String dayAsString(const Time::Day day) {
  switch (day) {
    case Time::kSunday: return "Sunday";
    case Time::kMonday: return "Monday";
    case Time::kTuesday: return "Tuesday";
    case Time::kWednesday: return "Wednesday";
    case Time::kThursday: return "Thursday";
    case Time::kFriday: return "Friday";
    case Time::kSaturday: return "Saturday";
  }
  return "(unknown day)";
}

void printTime() {
  // Get the current time and date from the chip.
  Time t = rtc.time();

  // Name the day of the week.
  const String day = dayAsString(t.day);

  // Format the time and date and insert into the temporary buffer.
  char buf[50];
  snprintf(buf, sizeof(buf), "%04d-%02d-%02d %02d:%02d:%02d",
           t.yr, t.mon, t.date,
           t.hr, t.min, t.sec);

  // Print the formatted string to serial so we can see the time.
  Serial.println(buf);
}

}  // namespace

void setup() {
  Serial.begin(9600);

  // Initialize a new chip by turning off write protection and clearing the
  // clock halt flag. These methods needn't always be called. See the DS1302
  // datasheet for details.
  rtc.writeProtect(false);
  rtc.halt(false);

  // Make a new time object to set the date and time.
  // Sunday, September 22, 2013 at 01:38:50.
  Time t(2013, 9, 22, 1, 38, 50, Time::kSunday);

  // Set the time and date on the chip.
  rtc.time(t);
}

// Loop and print the time every second.
void loop() {
  printTime();
  delay(1000);
}

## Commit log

2014-09-27 Added basic design template
    [Basic.dwg]
2014-10-04 added schematic
    [BOM.xlsx, Basic.dwg, clock1.sch]
2014-10-11 Updated design to have frosted triangle regions, screw holes
    [Basic.dwg]
2014-10-14 buttons work now, see comments
2014-10-18 added example designs and updated PCB schematic
    [Clock_Tom.dwg, Clock_Tom2.dwg, Clock_Updated_2.sch]
2014-10-18 organized documents into one folder
    [BOM.xlsx]
2014-10-25 Added two Duke designs
    [Clock_Duke.dwg, Clock_Duke_Name.dwg, Clock_Tom.dwg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]
2014-10-25 Added basic stand design
    [Basic_Stand.dwg]
2014-10-25 line color change
    [Clock_Tom2.dwg, Clock_Updated_3.sch]
2014-10-25 changed h,m,sec hands to use 12 LEDs on the strip instead of the entire strip in preparation for the code for the actual clock
2014-10-27 fixed 'vibrations' bug with buttons
    [AnalogClock.ino]
2014-10-31 rewired buttons without resistors, using INPUT_PULLUP; added a reset button for the second hand
2014-11-01 fixed button indexing issue (only uses 12 LEDs now instead of 13)
    [AnalogClock.ino]
2014-11-01 fixed buttons conflicting with time keeping
    [AnalogClock.ino]
2014-11-08 changed seconds reset button into a brightness setting button
2015-01-24 found out vdd and ledvdd were switched
    [Clock_Updated_3_Nets.brd, Clock_Updated_3_Nets.sch, Clock_Updated_3_board1.brd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]
2015-01-24 changed wires
    [Clock_Updated_3_Nets.brd, Clock_Updated_3_Nets.sch]
2015-01-31 switched LEDs clock direction to go from 11 -> 0 rather than 0 -> 11 because LEDs are indexed in CCW direction on circuit board
2015-02-17 added test files
    [Clock_Duke.dwg, Clock_Updated_3_Nets.brd, Clock_Updated_3_Nets.sch]
2015-02-17 fixed seconds hand scaling problem
    [AnalogClock.ino]
2015-02-17 attempted to fix minute hand color scaling problem when pressing the minutes button
    [AnalogClock.ino]
2015-02-21 changed stand
    [Basic with Screws.dwg, Basic_Stand_Updated.dwg]
2015-04-22 added designs to be laser-cut
    [Clock_DukeIEEE.dwg, Clock_DukeIEEE_clean.dwg, Clock_IEEE.dwg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]
2015-11-21 fixed clock direction bug after reverting to Nov-8-2014 commit
    [AnalogClock.ino]

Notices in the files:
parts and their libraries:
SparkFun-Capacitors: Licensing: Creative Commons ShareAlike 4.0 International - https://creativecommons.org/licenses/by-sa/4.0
